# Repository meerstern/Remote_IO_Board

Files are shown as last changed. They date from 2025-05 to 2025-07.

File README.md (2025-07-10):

# リモートIO基板
# Remote IO Board
Remote IO Board with Shift Register 

## 概要 
  * 本基板はIO信号をシリアル化してメイン基板とサブ基板間で同期する基板です  
  * メイン基板、サブ基板ともにそれぞれ8本の入力と出力を備えており、メイン基板とサブ基盤間で各信号のON/OFF状態が同期されます
  * 本基板はマイコンやFPGA等を使用せず、シフトレジスタ、タイマ、カウンタ等のICのみで構成されています  
  * ボタンやLED等のユーザ入出力の配線を省配線化する際に便利です  
  * 本基板を使用せずに8入力/8出力の信号をそのまま伝送すると一般的には計16本の信号線が必要となります  
  * 本基板を使用すると信号線3本のみで伝送することが可能です（同期クロック＋シリアルデータx2、電源線除く）
  * 本基板を使用すると電源線を含めても計5本の配線で双方向に8入力/8出力の信号を伝送できます  
  * 片方向のみの場合は信号線2本のみで伝送することが可能です（同期クロック＋シリアルデータx1※D0 or D1を未接続、電源線除く）  
  * 各入出力の動作確認用にそれぞれボタン及びLEDを備えています
  * 例えば、操作盤と制御盤が離れている場合に操作盤と制御盤間の省配線化が可能になります

## 仕様
  * 電源電圧DC2V~5.5V  
  * メイン基板とサブ基板でそれぞれ8入力/8出力  
  * メイン基板とサブ基板の電源は同一の電源電圧を供給してください  
  * 約1kHzの周期で双方向に同期します(内部クロック約8kHz、8bit+同期1bit)
  * 入力に74HC165、出力に74HC595を使用しているため、シリアル転送中に変換途中の信号出力を防止しています    
  * 入力ポートは基板内部でプルダウンされています  
  * メイン基板とサブ基板の伝送距離は最大数m程度を想定しています
  * メイン基板外形47.5mm x 38mm, M3x2(穴幅41mm)
  * サブ基板外形41.5mm x38mm, M3x2(穴幅35mm)

## 使用方法
  * 出荷時はメイン基板とサブ基板が一体になっています　　
  * 基板にはミシン目（スリット）が入っていますので必要に応じてカットして使用してください　　
  * メイン基板とサブ基板のSCK同士、D0同士、D1同士をケーブルで接続します  
  * 片方向のみで使用する場合はD0もしくはD1のどちらかを未接続で使用します  
  * メイン基板とサブ基板のVCCとGNDに電源を接続します 
  * 必要に応じてIN0-15にスイッチ、OUT0-15にLED等を配線してください  
  * 基板内部でプルダウンされているため、未使用の入力は未接続で使用します  
    
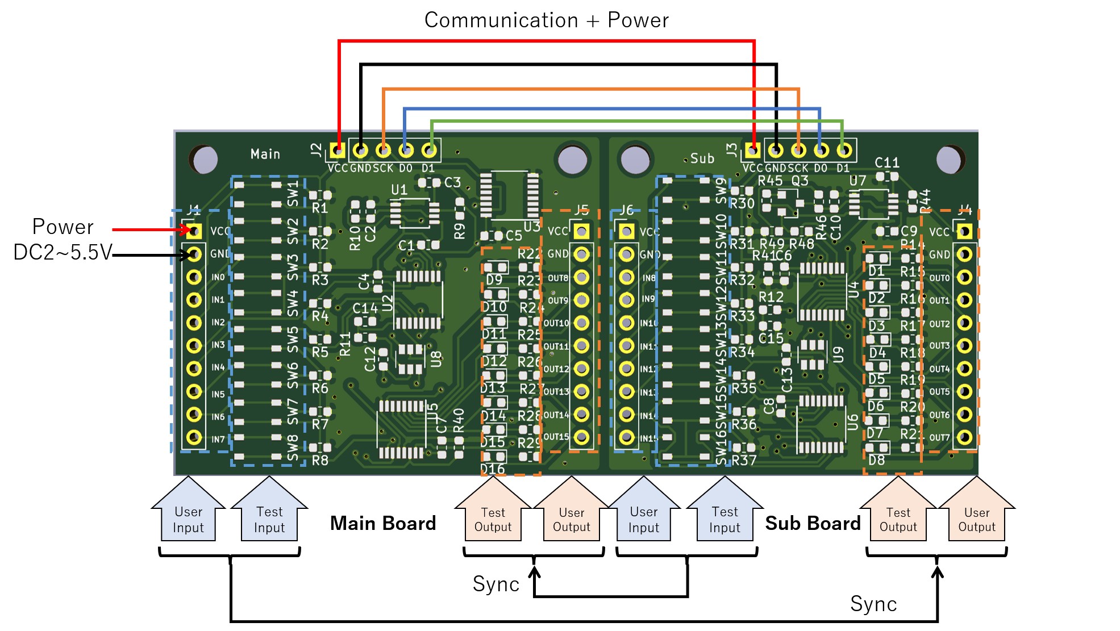
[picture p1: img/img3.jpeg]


## 注意 
  * ON/OFFのデジタル信号が同期されます。アナログ信号の同期はできません  
  * 電源投入直後は同期状態や出力が不安定な場合があります  
  * 伝送距離が長い場合やノイズ環境下等では信号同期が安定しない場合があります  
  * ノイズ環境下や長い伝送距離の場合は必要に応じて、シールドケーブルやフォトカプラ等でノイズ対策を追加してください  
  * 高い信頼性が求められる用途には使用しないでください    
  * メイン基板とサブ基板は必要に応じて分離して使用してください  
  * 分離の際や分離後のエッジ部分は鋭利なため、怪我をしないように注意してください    
  * 基板をカットする際はそれぞれの基板に過大な力が掛からない様にして下さい　　

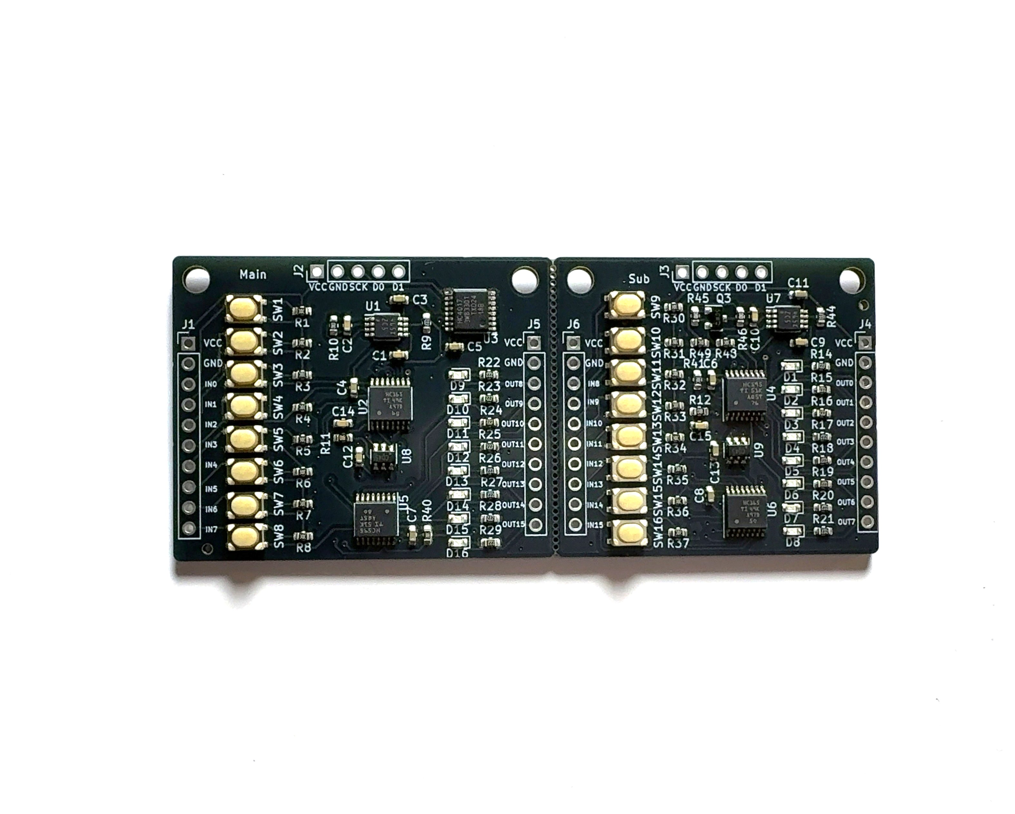
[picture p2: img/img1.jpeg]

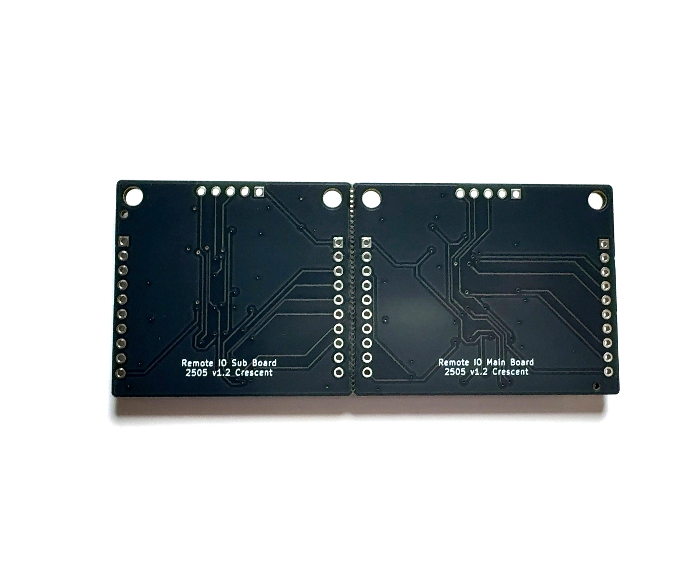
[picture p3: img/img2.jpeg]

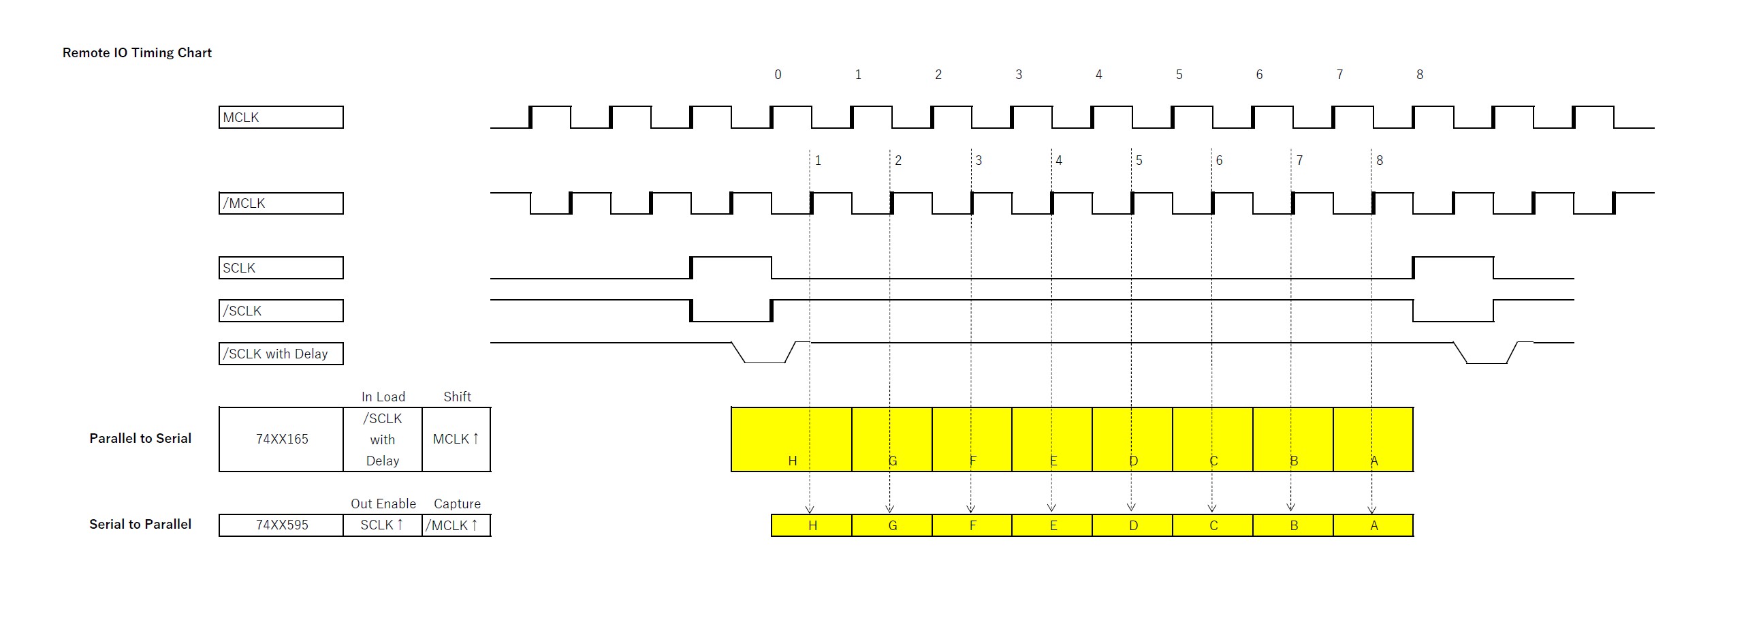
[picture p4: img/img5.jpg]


※LEDが高速に点滅しているように見えますが、実際はスイッチ状態に応じて点灯しています  

MIT Lisense

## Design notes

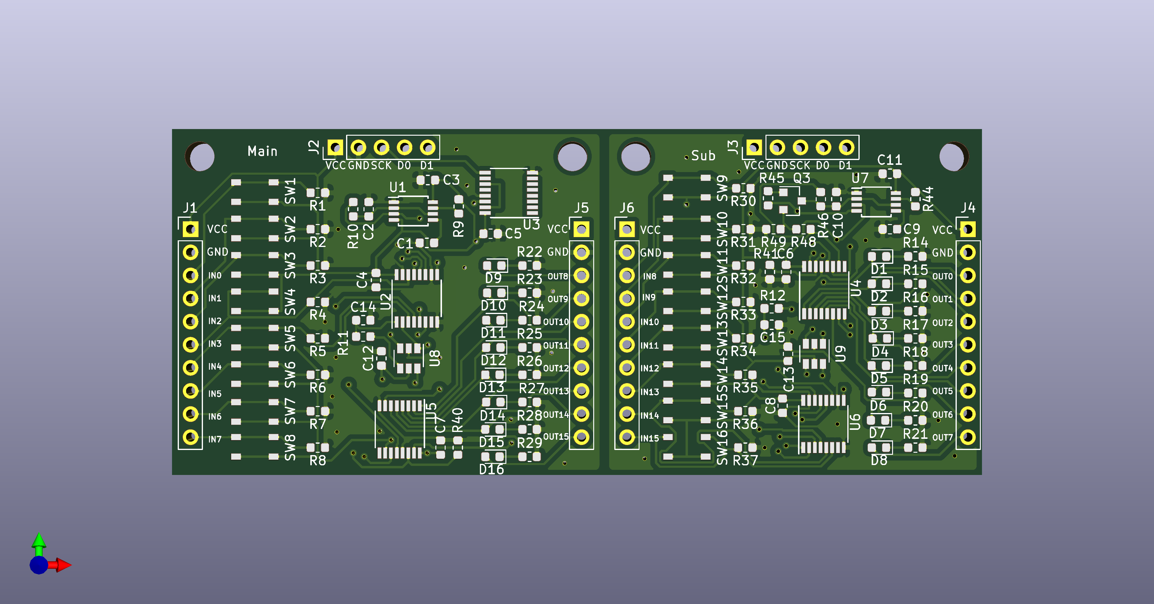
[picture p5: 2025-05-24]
pcb/ShiftRegRemoteIO/ShiftRegRemoteIO.png

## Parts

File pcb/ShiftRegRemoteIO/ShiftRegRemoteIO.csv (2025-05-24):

ID | 参照記号 | パッケージ | 数 | 名称 | Supplier and ref
1 | R12,R11 | R_0603_1608Metric | 2 | 1k
2 | C15,C14,C9,C1 | C_0603_1608Metric | 4 | 0.01u
3 | D16,D15,D14,D13,D12,D11,D10,D9,D8,D7,D6,D5,D4,D3,D2,D1 | LED_0603_1608Metric | 16 | LED_ALT
4 | U9,U8 | SOT-23-6 | 2 | 74AUC2G04
5 | C13,C12,C11,C8,C7,C6,C5,C4,C3 | C_0603_1608Metric | 9 | 0.1u
6 | U7,U1 | TSSOP-8_3x3mm_P0.65mm | 2 | NE555
7 | R49 | R_0603_1608Metric | 1 | 10k
8 | R48,R41,R40,R37,R36,R35,R34,R33,R32,R31,R30,R8,R7,R6,R5,R4,R3,R2,R1 | R_0603_1608Metric | 19 | 20k
9 | R46,R45,R10 | R_0603_1608Metric | 3 | 100k
10 | R44,R29,R28,R27,R26,R25,R24,R23,R22,R21,R20,R19,R18,R17,R16,R15,R14,R9 | R_0603_1608Metric | 18 | 2.2k
11 | Q3 | SOT-23 | 1 | BC807_PNP_BEC
12 | J3,J2 | PinHeader_1x05_P2.54mm_Vertical | 2 | Conn_01x05
13 | C10,C2 | C_0603_1608Metric | 2 | 1000p
14 | REF1,REF2,REF3,REF4 | MountingHole_3.2mm_M3 | 4 | MountingHole_3.2mm_M3
15 | U6,U2 | SSOP-16_3.9x4.9mm_P0.635mm | 2 | SN74HC165
16 | U5,U4 | SSOP-16_3.9x4.9mm_P0.635mm | 2 | 74HC595
17 | SW16,SW8 | SKRPACE010 | 2 | INPUT7
18 | SW15,SW7 | SKRPACE010 | 2 | INPUT6
19 | SW14,SW6 | SKRPACE010 | 2 | INPUT5
20 | SW13,SW5 | SKRPACE010 | 2 | INPUT4
21 | SW12,SW4 | SKRPACE010 | 2 | INPUT3
22 | SW11,SW3 | SKRPACE010 | 2 | INPUT2
23 | SW10,SW2 | SKRPACE010 | 2 | INPUT1
24 | SW9,SW1 | SKRPACE010 | 2 | INPUT0
25 | J6,J5,J4 | PinHeader_1x10_P2.54mm_Vertical | 3 | POW & OUTPUT
26 | U3 | SSOP-16_3.9x4.9mm_P0.635mm | 1 | CD4017
27 | J1 | PinHeader_1x10_P2.54mm_Vertical | 1 | POW & INPUT

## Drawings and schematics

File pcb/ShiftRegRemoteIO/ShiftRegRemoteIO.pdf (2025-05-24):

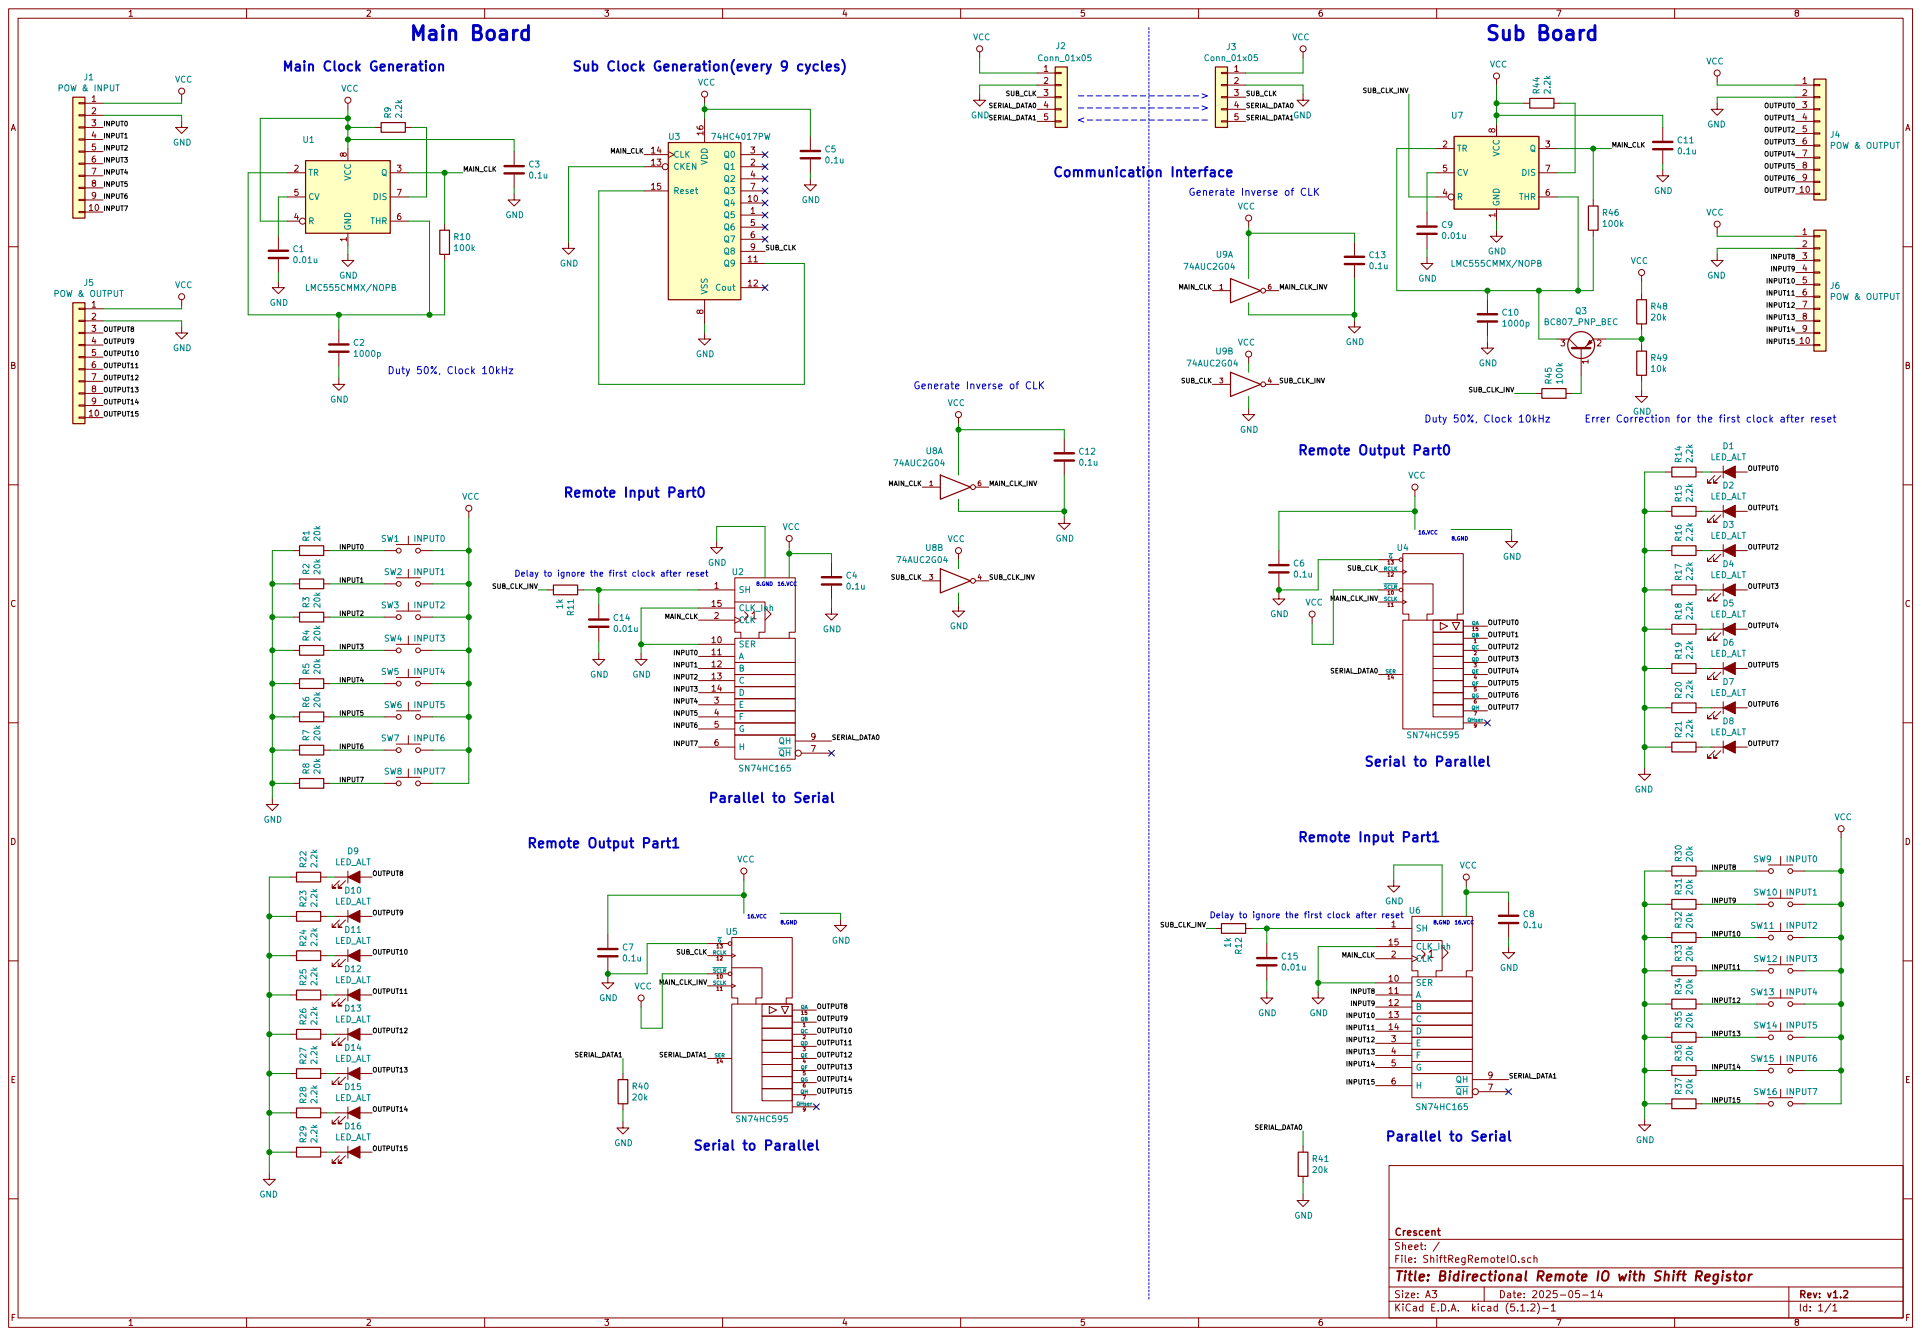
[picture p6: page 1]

Serial to Parallel Generate Inverse of CLK Remote Input Part0

Delay to ignore the first clock after reset

File: ShiftRegRemoteIO.sch Sheet: / Crescent

Id: 1/1 Title: Bidirectional Remote IO with Shift Registor

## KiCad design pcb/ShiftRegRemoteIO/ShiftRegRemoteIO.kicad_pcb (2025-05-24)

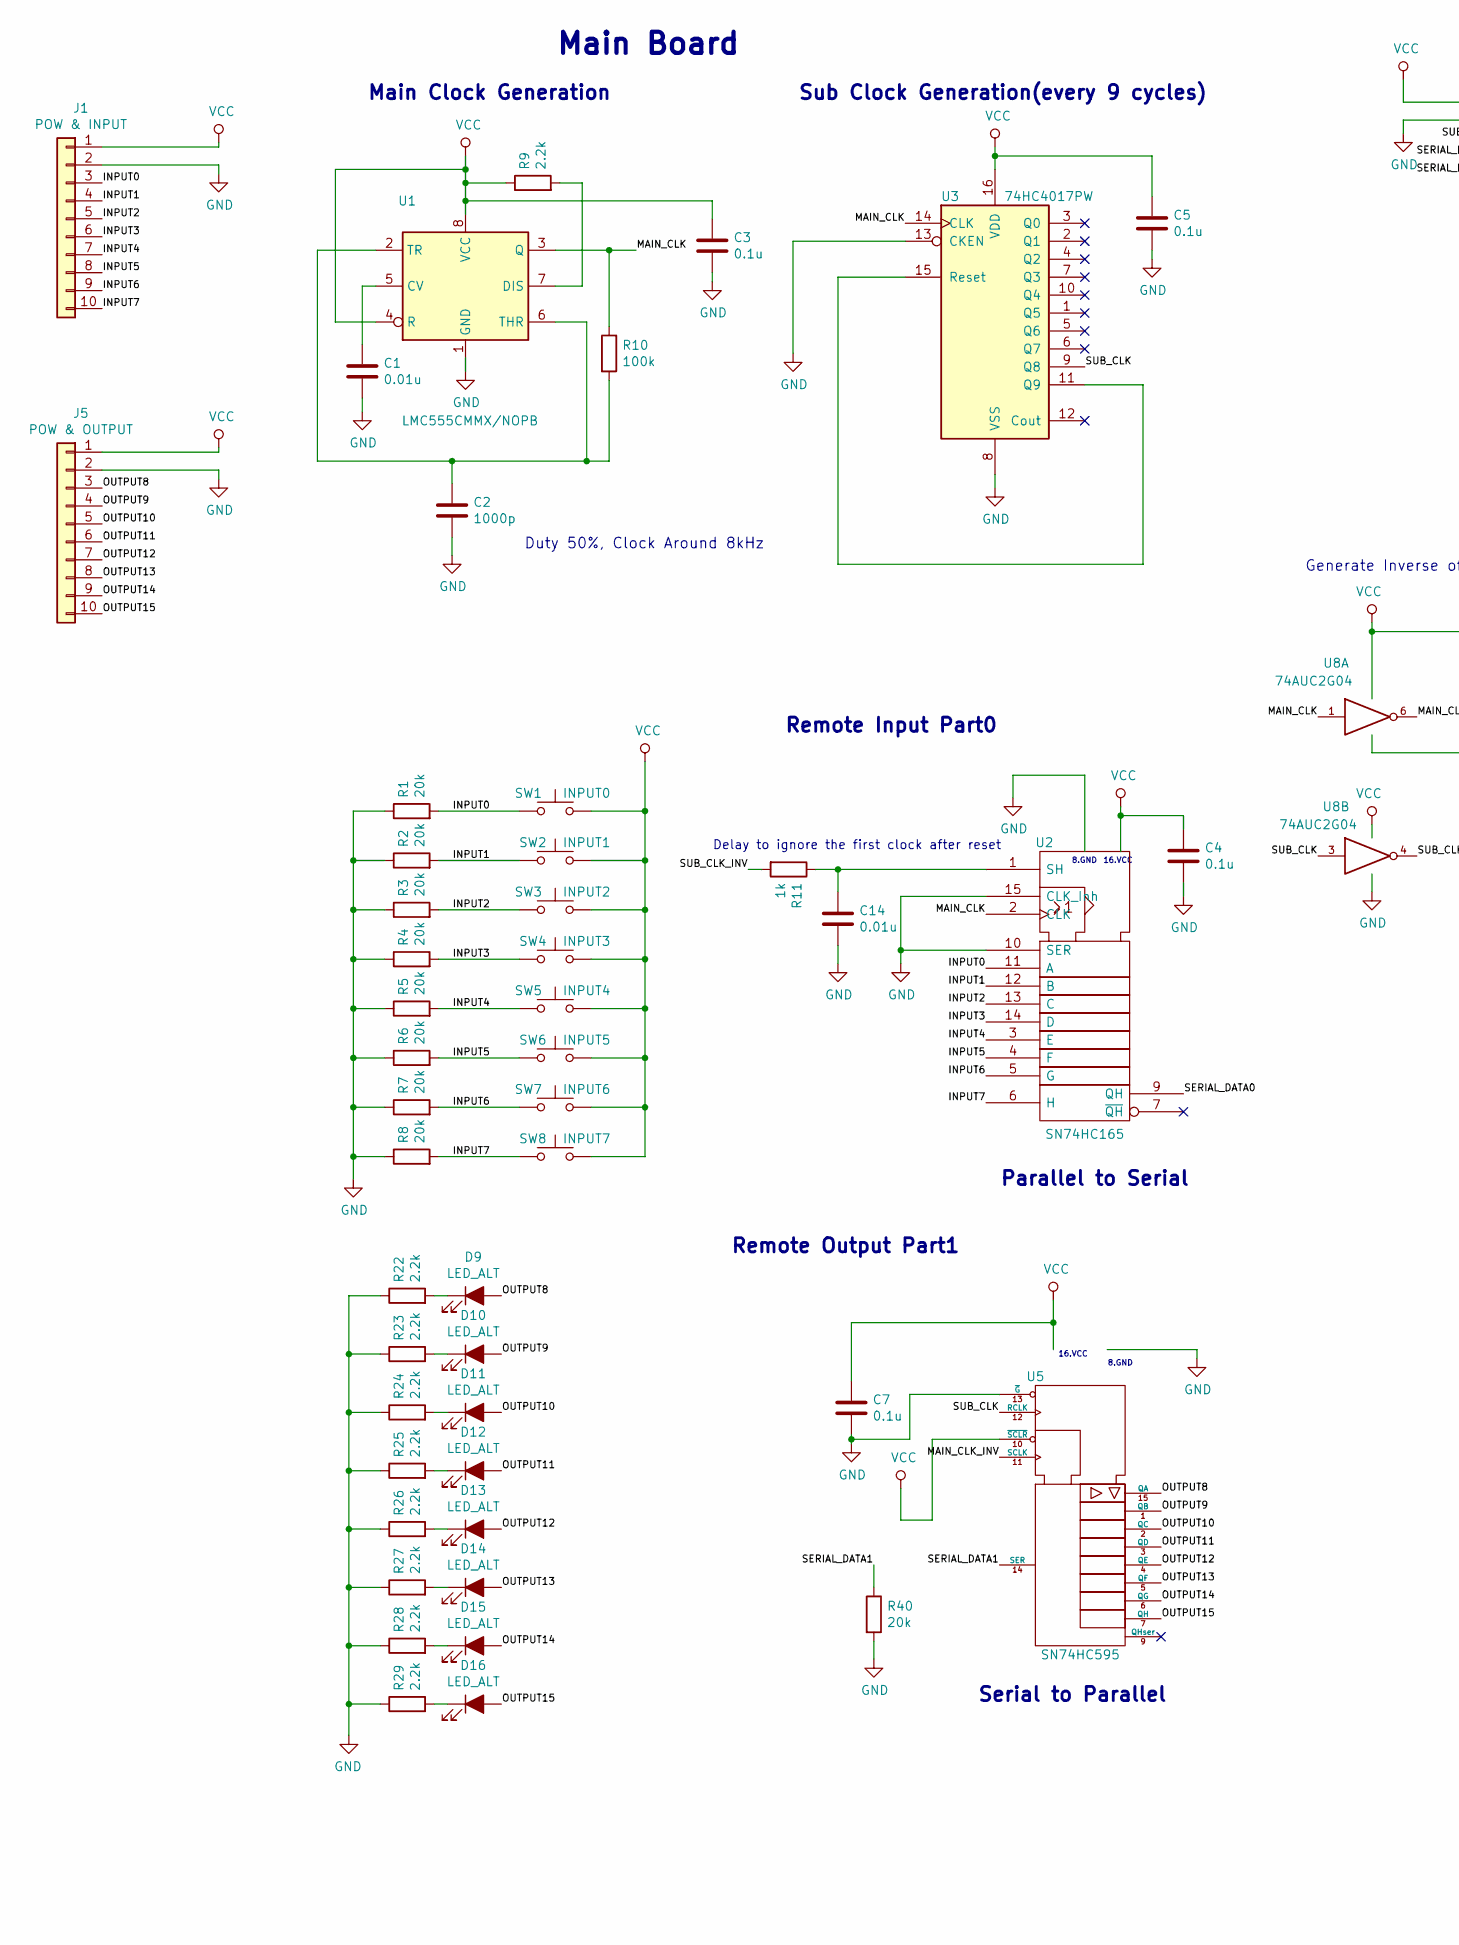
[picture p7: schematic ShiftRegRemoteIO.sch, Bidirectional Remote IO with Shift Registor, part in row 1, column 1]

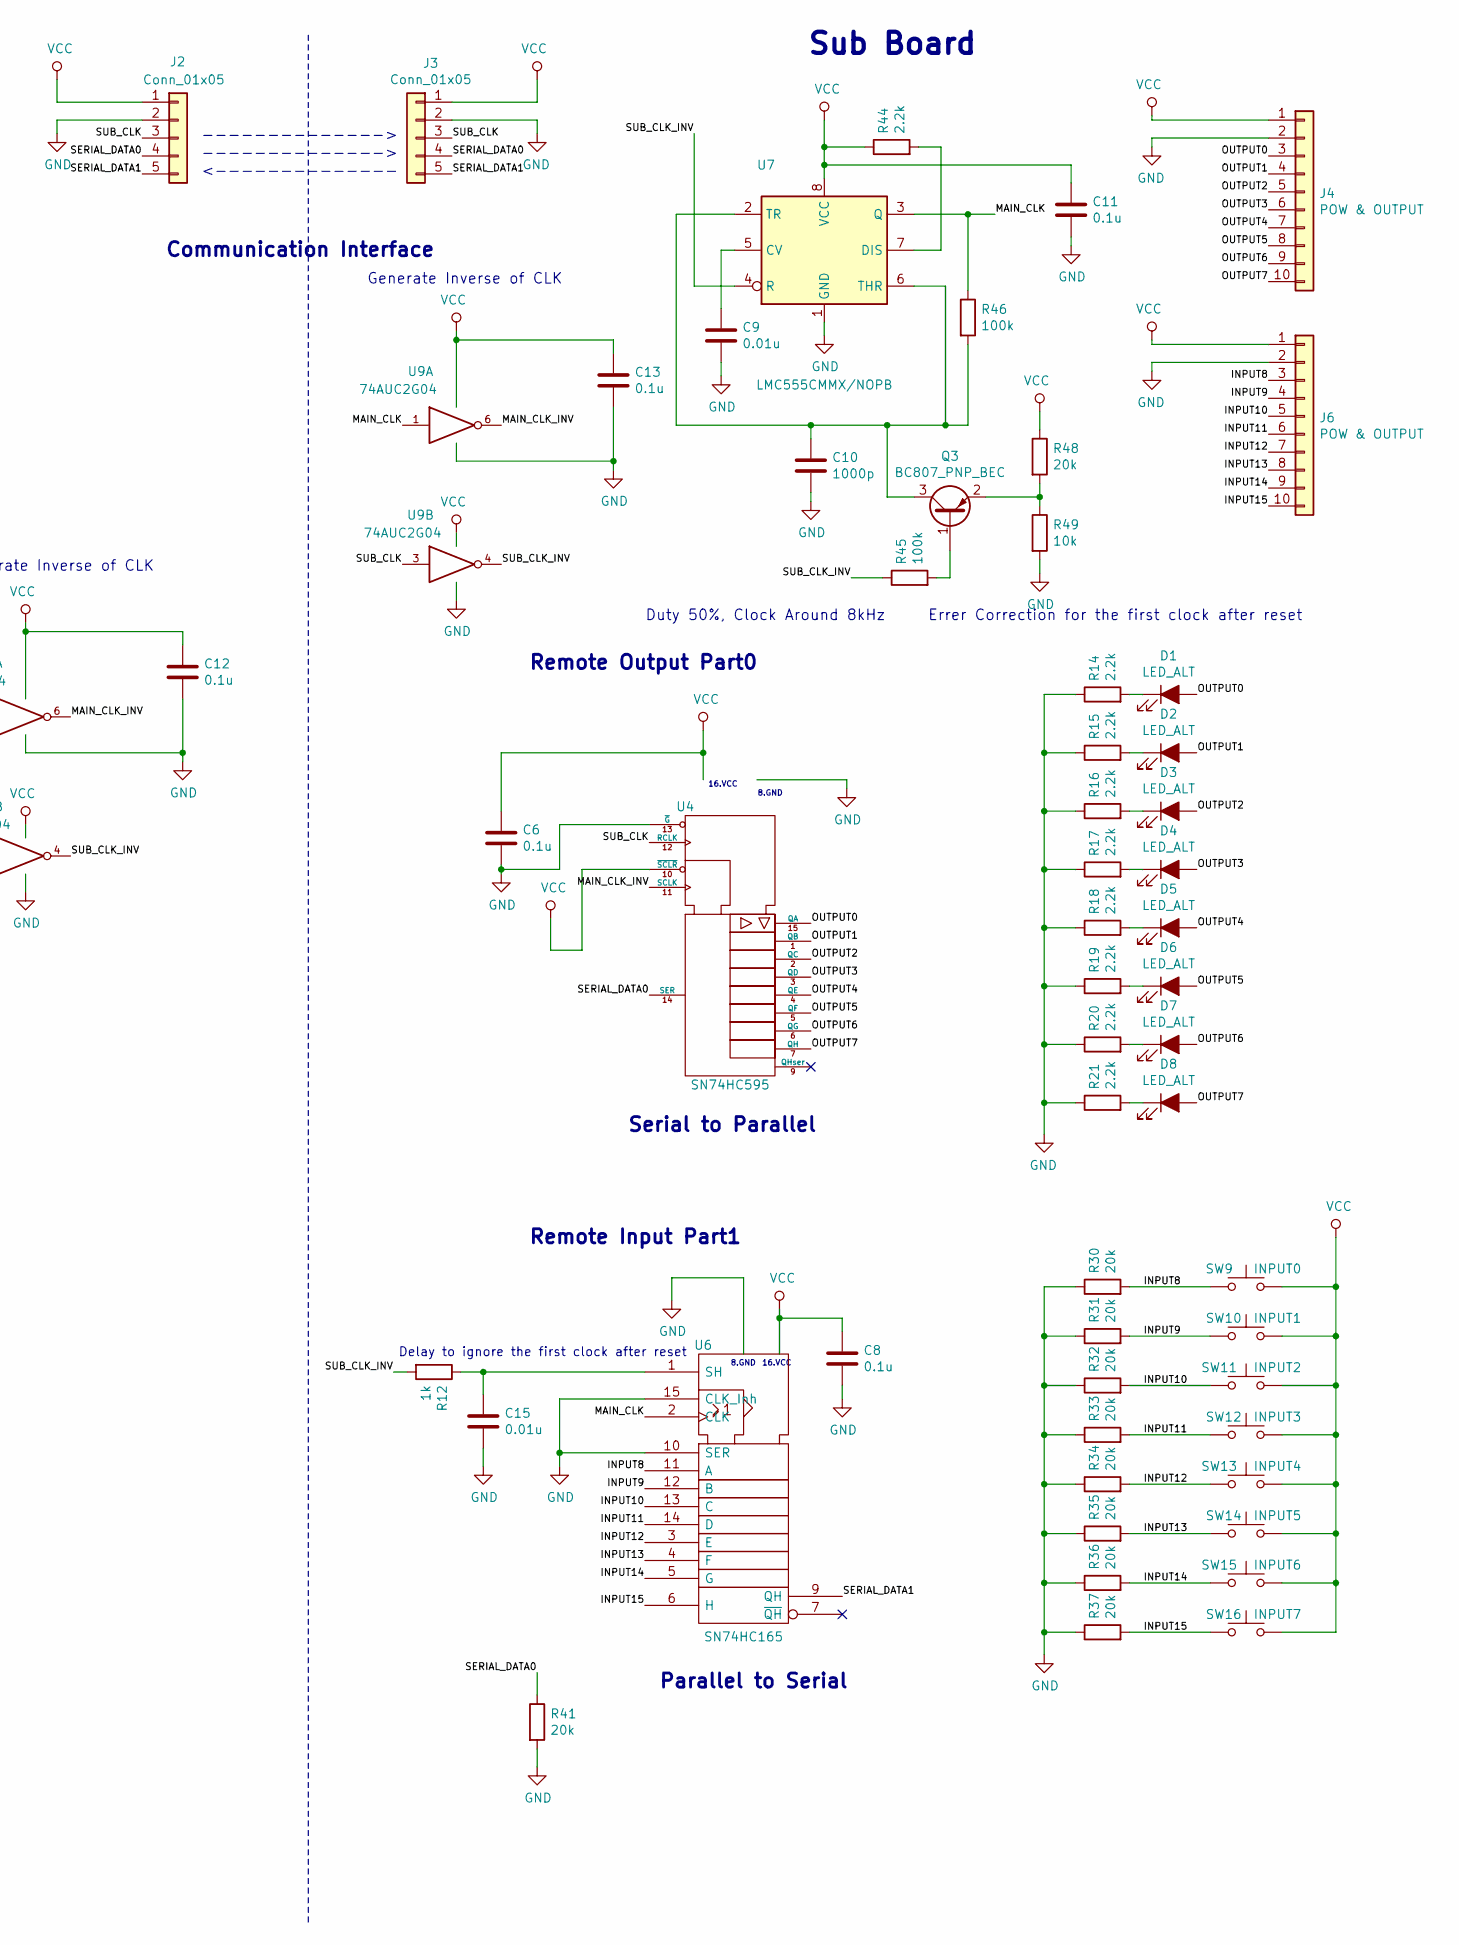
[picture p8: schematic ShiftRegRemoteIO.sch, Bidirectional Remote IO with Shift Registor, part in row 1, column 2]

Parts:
C1, C9, C14, C15: 0.01u; C_0603_1608Metric
C2, C10: 1000p; C_0603_1608Metric
C3, C4, C5, C6, C7, C8, C11, C12, C13: 0.1u; C_0603_1608Metric
D1, D2, D3, D4, D5, D6, D7, D8, D9, D10, D11, D12, D13, D14, D15, D16: LED_ALT; LED_0603_1608Metric
J1: POW & INPUT; PinHeader_1x10_P2.54mm_Vertical
J2, J3: Conn_01x05; PinHeader_1x05_P2.54mm_Vertical
J4, J5, J6: POW & OUTPUT; PinHeader_1x10_P2.54mm_Vertical
Q3: BC807_PNP_BEC; SOT-23
R1, R2, R3, R4, R5, R6, R7, R8, R30, R31, R32, R33, R34, R35, R36, R37, R40, R41, R48: 20k; R_0603_1608Metric
R9, R14, R15, R16, R17, R18, R19, R20, R21, R22, R23, R24, R25, R26, R27, R28, R29, R44: 2.2k; R_0603_1608Metric
R10, R45, R46: 100k; R_0603_1608Metric
R11, R12: 1k; R_0603_1608Metric
R49: 10k; R_0603_1608Metric
SW1, SW9: INPUT0; SKRPACE010
SW2, SW10: INPUT1; SKRPACE010
SW3, SW11: INPUT2; SKRPACE010
SW4, SW12: INPUT3; SKRPACE010
SW5, SW13: INPUT4; SKRPACE010
SW6, SW14: INPUT5; SKRPACE010
SW7, SW15: INPUT6; SKRPACE010
SW8, SW16: INPUT7; SKRPACE010
U1, U7: LMC555CMMX/NOPB; TSSOP-8_3x3mm_P0.65mm
U2, U6: SN74HC165; SSOP-16_3.9x4.9mm_P0.635mm
U3: 74HC4017PW; SSOP-16_3.9x4.9mm_P0.635mm
U4, U5: SN74HC595; SSOP-16_3.9x4.9mm_P0.635mm
U8, U9: 74AUC2G04; SOT-23-6

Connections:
/INPUT0: J1.3, R1.2, SW1.1, U2.11 (A)
/INPUT1: J1.4, R2.2, SW2.1, U2.12 (B)
/INPUT2: J1.5, R3.2, SW3.1, U2.13 (C)
/INPUT3: J1.6, R4.2, SW4.1, U2.14 (D)
/INPUT4: J1.7, R5.2, SW5.1, U2.3 (E)
/INPUT5: J1.8, R6.2, SW6.1, U2.4 (F)
/INPUT6: J1.9, R7.2, SW7.1, U2.5 (G)
/INPUT7: J1.10, R8.2, SW8.1, U2.6 (H)
/INPUT8: J6.3, R30.2, SW9.1, U6.11 (A)
/INPUT9: J6.4, R31.2, SW10.1, U6.12 (B)
/INPUT10: J6.5, R32.2, SW11.1, U6.13 (C)
/INPUT11: J6.6, R33.2, SW12.1, U6.14 (D)
/INPUT12: J6.7, R34.2, SW13.1, U6.3 (E)
/INPUT13: J6.8, R35.2, SW14.1, U6.4 (F)
/INPUT14: J6.9, R36.2, SW15.1, U6.5 (G)
/INPUT15: J6.10, R37.2, SW16.1, U6.6 (H)
/MAIN_CLK: R10.1, R46.1, U1.3 (Q), U2.2 (CLK), U3.14 (CLK), U6.2 (CLK), U7.3 (Q), U8.1, U9.1
/MAIN_CLK_INV: U4.11 (SCLK), U5.11 (SCLK), U8.6, U9.6
/OUTPUT0: D1.2 (A), J4.3, U4.15 (QA)
/OUTPUT1: D2.2 (A), J4.4, U4.1 (QB)
/OUTPUT2: D3.2 (A), J4.5, U4.2 (QC)
/OUTPUT3: D4.2 (A), J4.6, U4.3 (QD)
/OUTPUT4: D5.2 (A), J4.7, U4.4 (QE)
/OUTPUT5: D6.2 (A), J4.8, U4.5 (QF)
/OUTPUT6: D7.2 (A), J4.9, U4.6 (QG)
/OUTPUT7: D8.2 (A), J4.10, U4.7 (QH)
/OUTPUT8: D9.2 (A), J5.3, U5.15 (QA)
/OUTPUT9: D10.2 (A), J5.4, U5.1 (QB)
/OUTPUT10: D11.2 (A), J5.5, U5.2 (QC)
/OUTPUT11: D12.2 (A), J5.6, U5.3 (QD)
/OUTPUT12: D13.2 (A), J5.7, U5.4 (QE)
/OUTPUT13: D14.2 (A), J5.8, U5.5 (QF)
/OUTPUT14: D15.2 (A), J5.9, U5.6 (QG)
/OUTPUT15: D16.2 (A), J5.10, U5.7 (QH)
/SERIAL_DATA0: J2.4, J3.4, R41.1, U2.9 (QH), U4.14 (SER)
/SERIAL_DATA1: J2.5, J3.5, R40.1, U5.14 (SER), U6.9 (QH)
/SUB_CLK: J2.3, J3.3, U3.9 (Q8), U4.12 (RCLK), U5.12 (RCLK), U8.3, U9.3
/SUB_CLK_INV: R11.2, R12.2, R45.1, U7.4 (R), U8.4, U9.4
GND: C1.2, C2.2, C3.2, C4.2, C5.2, C6.2, C7.2, C8.2, C9.2, C10.2, C11.2, C12.2, C13.2, C14.2, C15.2, J1.2, J2.2, J3.2, J4.2, J5.2, J6.2, R1.1, R2.1, R3.1, R4.1, R5.1, R6.1, R7.1, R8.1, R14.1, R15.1, R16.1, R17.1, R18.1, R19.1, R20.1, R21.1, R22.1, R23.1, R24.1, R25.1, R26.1, R27.1, R28.1, R29.1, R30.1, R31.1, R32.1, R33.1, R34.1, R35.1, R36.1, R37.1, R40.2, R41.2, R49.2, U1.1 (GND), U2.8 (GND), U2.10 (SER), U2.15 (CLK_Inh), U3.8 (VSS), U3.13 (CKEN), U4.8 (GND), U4.13 (~G), U5.8 (GND), U5.13 (~G), U6.8 (GND), U6.10 (SER), U6.15 (CLK_Inh), U7.1 (GND), U8.2 (GND), U9.2 (GND)
unnamed: C1.1, U1.5 (CV)
unnamed: C2.1, R10.2, U1.2 (TR), U1.6 (THR)
unnamed: C9.1, U7.5 (CV)
unnamed: C10.1, Q3.3 (C), R46.2, U7.2 (TR), U7.6 (THR)
unnamed: C14.1, R11.1, U2.1 (SH)
unnamed: C15.1, R12.1, U6.1 (SH)
unnamed: D1.1 (K), R14.2
unnamed: D2.1 (K), R15.2
unnamed: D3.1 (K), R16.2
unnamed: D4.1 (K), R17.2
unnamed: D5.1 (K), R18.2
unnamed: D6.1 (K), R19.2
unnamed: D7.1 (K), R20.2
unnamed: D8.1 (K), R21.2
unnamed: D9.1 (K), R22.2
unnamed: D10.1 (K), R23.2
unnamed: D11.1 (K), R24.2
unnamed: D12.1 (K), R25.2
unnamed: D13.1 (K), R26.2
unnamed: D14.1 (K), R27.2
unnamed: D15.1 (K), R28.2
unnamed: D16.1 (K), R29.2
unnamed: Q3.1 (B), R45.2
unnamed: Q3.2 (E), R48.2, R49.1
unnamed: R9.2, U1.7 (DIS)
unnamed: R44.2, U7.7 (DIS)
unnamed: U3.11 (Q9), U3.15 (Reset)
VCC: C3.1, C4.1, C5.1, C6.1, C7.1, C8.1, C11.1, C12.1, C13.1, J1.1, J2.1, J3.1, J4.1, J5.1, J6.1, R9.1, R44.1, R48.1, SW1.2, SW2.2, SW3.2, SW4.2, SW5.2, SW6.2, SW7.2, SW8.2, SW9.2, SW10.2, SW11.2, SW12.2, SW13.2, SW14.2, SW15.2, SW16.2, U1.4 (R), U1.8 (VCC), U2.16 (VCC), U3.16 (VDD), U4.10 (~SCLR), U4.16 (VCC), U5.10 (~SCLR), U5.16 (VCC), U6.16 (VCC), U7.8 (VCC), U8.5 (VCC), U9.5 (VCC)

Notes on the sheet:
Main Clock Generation
Sub Clock Generation(every 9 cycles)
Parallel to Serial
Duty 50%, Clock Around 8kHz
Communication Interface
Serial to Parallel
Generate Inverse of CLK
Remote Input Part0
Remote Output Part0
16.VCC
8.GND
Remote Output Part1
Remote Input Part1
Errer Correction for the first clock after reset
Sub Board
Main Board
Delay to ignore the first clock after reset
-------------->
<--------------

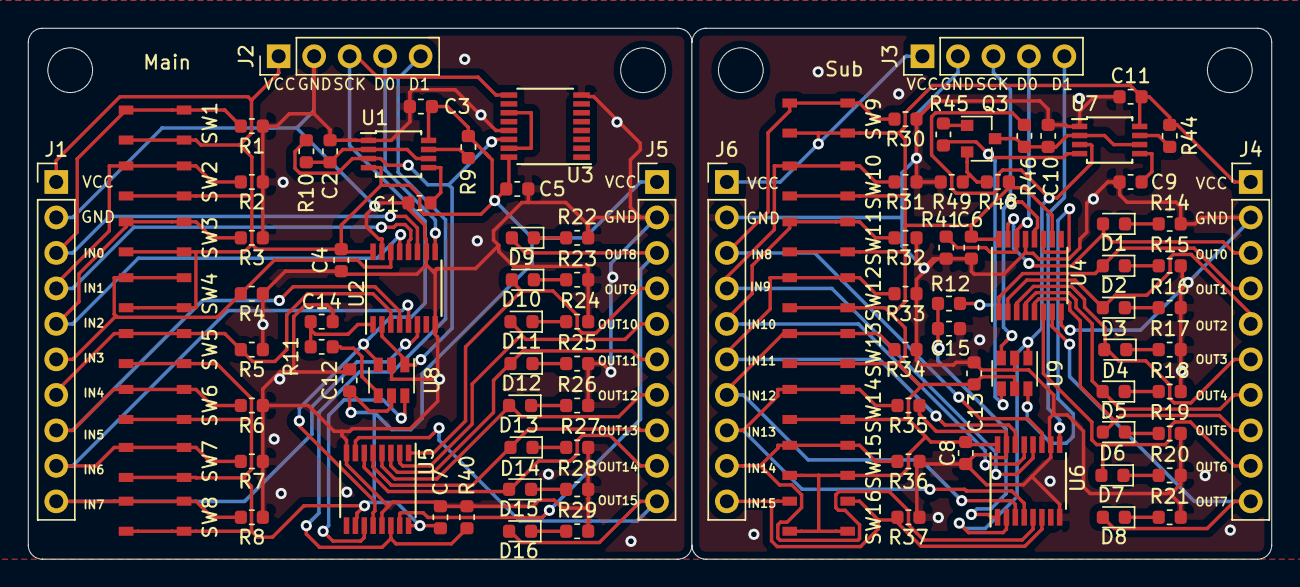
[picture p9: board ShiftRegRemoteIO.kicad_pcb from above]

Board: 2 copper layers, 89.0 x 38.0 mm, 110 parts (0 on the bottom side), 67 nets.

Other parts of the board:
REF1, REF2, REF3, REF4: MountingHole_3.2mm_M3
